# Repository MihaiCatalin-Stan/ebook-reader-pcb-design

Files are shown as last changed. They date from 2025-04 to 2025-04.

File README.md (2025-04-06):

335CA Mihai-Catalin Stan
# OpenBook EBook Reader
This project contains the 2D and 3D Hardware design of an ebook reader, alongside the manufacturing files and some images of the product.
## Block Diagram
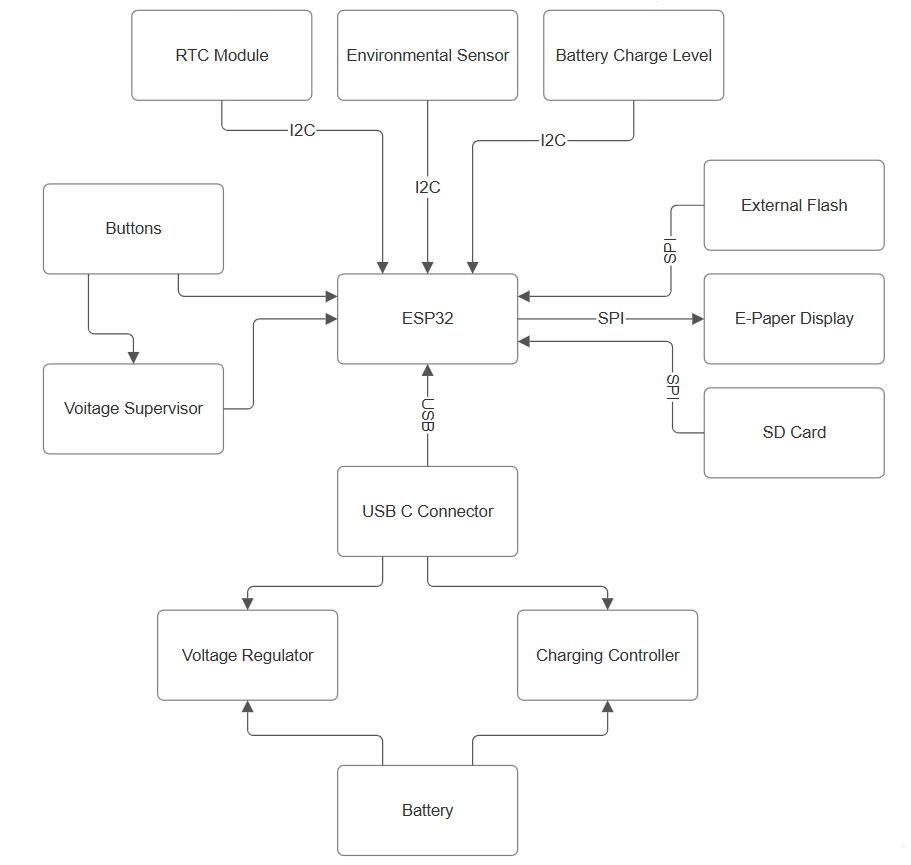
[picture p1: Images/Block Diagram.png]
Block Diagram


## Bill of Materials
|Component|Description|Buy Here|Datasheet|
|---|---|---|---|
|ESP32_WROVER_EAGLE-LTSPICE_RR0402 | Resistor | https://eu.mouser.com/ProductDetail/Vishay-Beyschlag/MCS04020D9101BE000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  | https://www.vishay.com/docs/28700/mcx0x0xpre.pdf
|EAGLE-LTSPICE_CC0402 | Capacitor | https://eu.mouser.com/ProductDetail/KEMET/C0402C475K8PACTU?qs=ulEaXIWI0c9ebKRT3r3htg%3D%3D | https://eu.mouser.com/datasheet/2/447/KEM_C1006_X5R_SMD-3316465.pdf
|ESP32C6_VARISTORCN1812 | Varistor | https://eu.mouser.com/ProductDetail/Schurter/PFMF.050.2?qs=1auRipcfynCums5v1iucSA%3D%3D | https://eu.mouser.com/datasheet/2/358/typ_PFMF-1275918.pdf
|CPH3225A | Capacitor | https://eu.mouser.com/ProductDetail/Seiko-Semiconductors/CPH3225A?qs=3etwrb1wR%252BhUOph6lAO7eg%3D%3D | https://eu.mouser.com/datasheet/2/360/Seiko_Instruments_MicroBattery_E_20230330_2024Jan_-3561061.pdf
|RCL_CPOL-EUCT3528 | Capacitor | https://eu.mouser.com/ProductDetail/Nichicon/LGN2W101MELA25?qs=Fe64Qgzkstf1zMszMsgRoA%3D%3D | https://eu.mouser.com/datasheet/2/293/e_lgn-3082370.pdf
|ADAFRUIT_LEDCHIP-LED0603 | LED | https://eu.mouser.com/ProductDetail/ams-OSRAM/KG-EELP41.22-PHRH-35-A8J8-20-R18?qs=ZcfC38r4Posajg8ZvCDQkg%3D%3D | https://eu.mouser.com/datasheet/2/588/KG_EELP41_22_EN-3572852.pdf
|ESP32_WROVER_SPARKFUN-DISCRETESEMI_MOSFET_PCH-DMG2305UX-7 | Transistor | https://eu.mouser.com/ProductDetail/Diodes-Incorporated/DMG2305UX-7?qs=L1DZKBg7t5F%2FNBHrjfxC%252Bg%3D%3D | https://www.diodes.com/assets/Datasheets/DMG2305UX.pdf
|SI1308EDL-T1-GE3 | Transistor | https://eu.mouser.com/ProductDetail/Vishay-Semiconductors/SI1308EDL-T1-GE3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 | https://www.vishay.com/docs/63399/si1308edl.pdf
| 744043680IND_4828-WE-TPC_WRE | Coil | https://eu.mouser.com/ProductDetail/Wurth-Elektronik/744043680?qs=PGXP4M47uW6VkZq%252BkzjrHA%3D%3D | https://www.we-online.com/components/products/datasheet/744043680.pdf
|112A-TAAR-R03_ATTEND | SD Card Mount | https://store.comet.srl.ro/Catalogue/Product/43497/ | https://store.comet.srl.ro/Catalogue/Product/43497/
|SAMACSYS_PARTS_USB4110-GF-A | USB Connector | https://eu.mouser.com/ProductDetail/GCT/USB4110-GF-A?qs=KUoIvG%2F9IlYiZvIXQjyJeA%3D%3D | https://eu.mouser.com/datasheet/2/837/GCT_USB4110_Product_Drawing___20k_cycles-3455479.pdf
|XC6220A331MR-G | LDO Voltage Regulator | https://eu.mouser.com/ProductDetail/Torex-Semiconductor/XC6220A331MR-G?qs=AsjdqWjXhJ8ZSWznL1J0gg%3D%3D | https://eu.mouser.com/datasheet/2/760/xc6220-3371556.pdf
|W25Q512JVEIQ | Flash Memory | https://eu.mouser.com/ProductDetail/Winbond/W25Q512JVEIQ?qs=l7cgNqFNU1jw6svr3at6tA%3D%3D | https://eu.mouser.com/datasheet/2/949/Winbond_W25Q512JV_Datasheet-3240039.pdf
|USBLC6-2SC6Y | ESD Protection | https://eu.mouser.com/ProductDetail/STMicroelectronics/USBLC6-2SC6Y?qs=gNDSiZmRJS%2FOgDexvXkdow%3D%3D | https://eu.mouser.com/datasheet/2/389/usblc6_2sc6y-1852505.pdf
|MCP73831 | Battery Controller | https://eu.mouser.com/ProductDetail/Microchip-Technology/MCP73831T-2ATI-MC?qs=yUQqVecv4qs9k7ug0bEXiw%3D%3D | https://eu.mouser.com/datasheet/2/268/MCP73831_Family_Data_Sheet_DS20001984H-3441711.pdf
|MAX17048G+T10 | Battery Management | https://eu.mouser.com/ProductDetail/Analog-Devices-Maxim-Integrated/MAX17048G%2bT10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 | https://eu.mouser.com/datasheet/2/609/MAX17048_MAX17049-3469099.pdf
|FH34SRJ | E-Paper Display Header | https://eu.mouser.com/ProductDetail/Hirose-Connector/FH34SRJ-7S-0.5SH50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 | https://eu.mouser.com/datasheet/2/185/FH34SRJ_7S_0_5SH_50__CL0580_1200_0_50_2DDrawing_00-1615127.pdf
|ESP32_WROVER_AVX---SD0805S020S1R0_AVX_SD0805S020S1R0_0_0AVX_SD0805S020S1R0_0_0 | Diode | https://eu.mouser.com/ProductDetail/ROHM-Semiconductor/SCS310AMC7G?qs=iLKYxzqNS75xiccEgNnX2g%3D%3D | https://fscdn.rohm.com/en/products/databook/datasheet/discrete/sic/sbd/scs310am-e.pdf
|ESP32-C6-WROOM-1-N8 | MicroController | https://eu.mouser.com/ProductDetail/Espressif-Systems/ESP32-C6?qs=Imq1NPwxi75noDtUpuVuWw%3D%3D | https://eu.mouser.com/datasheet/2/891/esp32_c6_datasheet_en-3304070.pdf
|DS3231SN# | RTC Module | https://eu.mouser.com/ProductDetail/Analog-Devices-Maxim-Integrated/DS3231SN?qs=1eQvB6Dk1vhUlr8%2FOrV0Fw%3D%3D | https://eu.mouser.com/datasheet/2/609/DS3231-3421123.pdf
|ESP32_WROVER_BME680_BME680 | Integrated Environmental Unit | https://eu.mouser.com/ProductDetail/M5Stack/U001-C?qs=e8oIoAS2J1R2mB7ZY1%252BSZg%3D%3D | https://docs.m5stack.com/en/unit/envIII
| BD5229G-TR | Voltage Detector | https://eu.mouser.com/ProductDetail/ROHM-Semiconductor/BD5229G-TR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 | https://fscdn.rohm.com/en/products/databook/datasheet/ic/power/voltage_detector/bd52xxg-e.pdf

## Hardware Details
* **MicroController - ESP32-C6-WROOM-1-N8:**
    * Pins are being used to communicate as follows:
        | Pin  | Signal       | Connected Component |
        |------|--------------|---------------------|
        | IO00 | INT_RTC      | RTC Module          |
        | IO01 | 32KHZ        | RTC Module          |
        | IO02 | MISO         | Flash, SD Card      |
        | IO03 | EPD_BUSY     | EPD                 |
        | IO04 | SS_SD        | SD Card             |
        | IO05 | EPD_DC       | EPD                 |
        | IO06 | SCK          | Flash, SD Card, BME688 |
        | IO07 | MOSI         | Flash, SD Card, EPD |
        | IO08 | GPIO8 / GND  | -                   |
        | IO09 | -            | -                   |
        | IO10 | EPD_CS       | EPD                 |
        | IO11 | FLASH_CS     | Flash               |
        | IO12 | USB_D-       | USB_C Connector     |
        | IO13 | USB_D+       | USB_C Connector     |
        | IO15 | IO/CHANGE    | Button              |
        | IO16 | TX           | -                   |
        | IO17 | RX           | -                   |
        | IO18 | RTC_RST      | RTC Module          |
        | IO19 | I2C_PW       | BME688              |
        | IO20 | EPD_3V3_C    | EPD                 |
        | IO21 | SDA          | RTC, BME688, Battery Level |
        | IO22 | SCL          | RTC, BME688, Battery Level |
        | IO23 | EPD_RST      | EPD                 |
    * The following Communication Protocols were used:
        | Protocol | Components |
        |----------|------------|
        | I2C      | RTC, BME688, Battery Level |
        | SPI      | Flash, SD Card, EPD |
        | USB      | USB_C Connector (Power) |
* **RTC Module:**
    * Communicates through `I2C` with the uC
        | Pin  | Signal       |
        |------|--------------|
        |Pin1| 32KHZ|
        |Pin3| INT_RTC|
        |Pin4| RTC_RST|
        |Pin14| VRTC|
        |Pin15| SDA|
        |Pin16| SCL|
* **Flash Module:**
    * Communicates through `SPI` with the uC and the other connected components
        | Pin  | Signal       |
        |------|--------------|
        |Pin1| FLASH_CS|
        |Pin2| MISO|
        |Pin5| MOSI|
        |Pin6| SCK|
* **SD Card Module:**
    * Communicates through `SPI` with the uC and the other connected components
        | Pin  | Signal       |
        |------|--------------|
        |P2| SS_SD|
        |P3| MOSI|
        |P5| SCK|
        |P7| MISO|
* **E-Paper Display:**
    * Communicates through `SPI` with the uC and the memory modules
        | Pin  | Signal       |
        |------|--------------|
        |Pin2| GDR|
        |Pin3| RESE|
        |Pin9| EPD_BUSY|
        |Pin10| EPD_RST|
        |Pin11| EPD_DC|
        |Pin12| EPD_CS|
        |Pin13| SCK|
        |Pin14| MOSI|
        |Pin15-16| EPD_3v3|
        |Pin21| PREVGH|
        |Pin23| PREVGL|
* **Battery Sensor:**
    * Checks the battery level and send data to the uC also with `I2C`
        | Pin  | Signal       |
        |------|--------------|
        |Pin2| VBAT|
        |Pin3| VBAT|
        |Pin7| SCL|
        |Pin8| SDA|
* **LDO - Voltage Regulator:**
    * Doesn't communicate with the uC but lowers the 5V to 3.3V for the uC and the attached modules
* **Environmental Sensor:**
    * Communicates through `I2C` with the uC and also with the RTC
        | Pin  | Signal       |
        |------|--------------|
        |Pin2| I2C_PW|
        |Pin3| SDA|
        |Pin4| SCL|
        |Pin6| I2C_PW|
        |Pin8| I2C_PW|
* **USB-C Connector:**
    * Power input for charging the battery
        | Pin  | Signal       |
        |------|--------------|
        |B4| VUSB|
        |B6| DP|
        |B7| DN|
        |B9| VUSB|
        |A4| VUSB|
        |A6| DP|
        |A7| DN|
        |A9| VUSB|
* **Buttons:**
    * Controls reset, boot and io/change signals by sending them to the uC when pressed

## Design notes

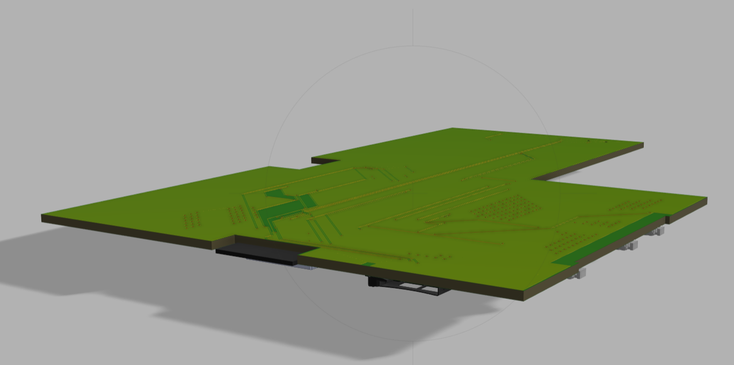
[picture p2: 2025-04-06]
Images/PCB Front View.png

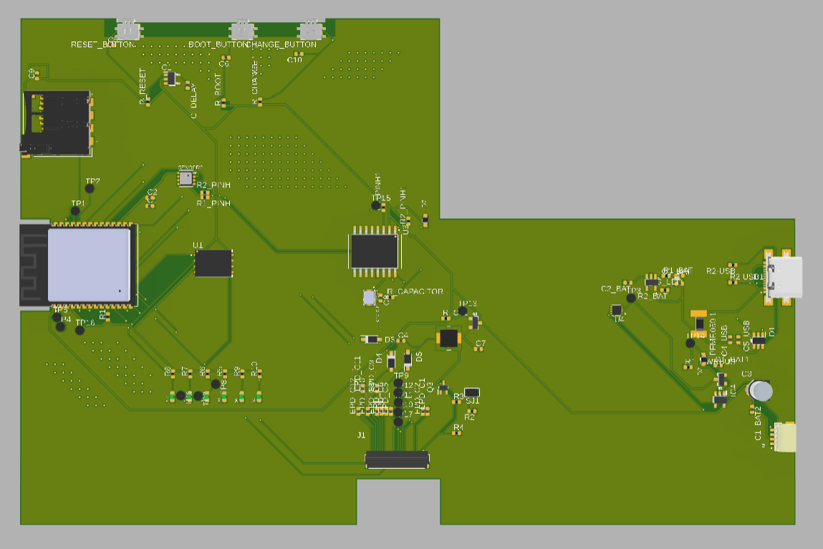
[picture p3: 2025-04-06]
Images/PCB Ortographic Top Layer.png

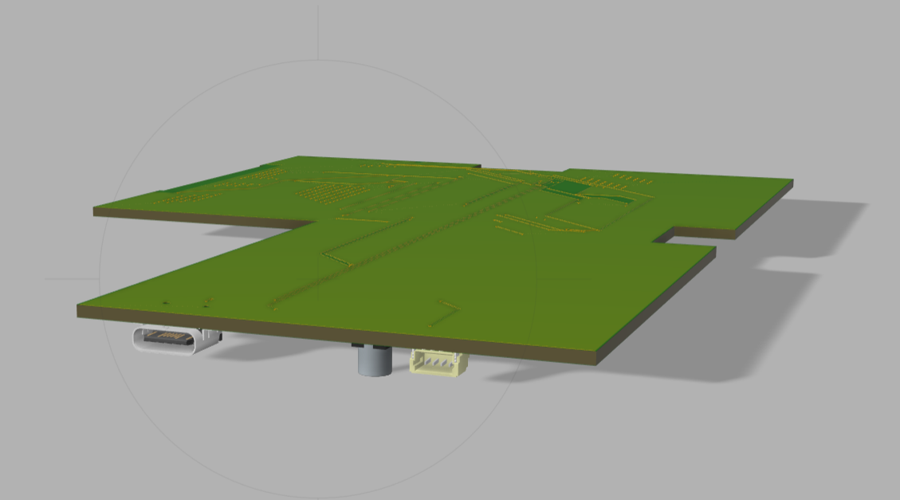
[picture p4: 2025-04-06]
Images/PCB Back View.png

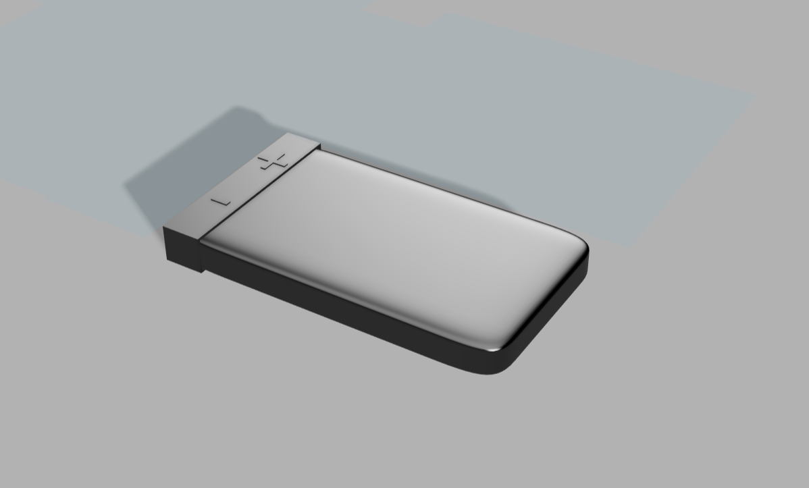
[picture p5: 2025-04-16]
Images/Battery.png

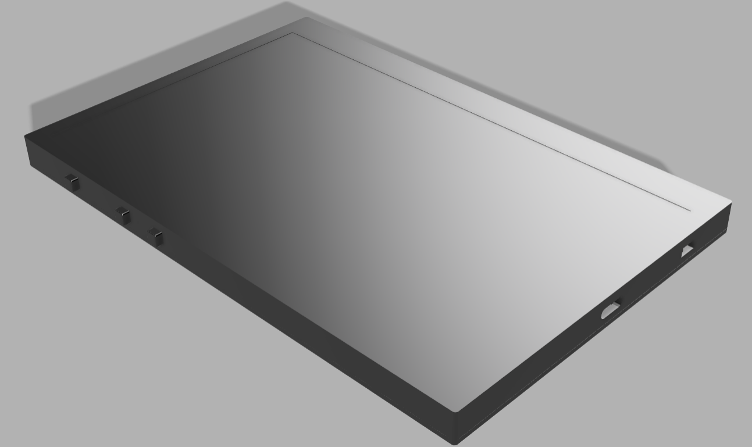
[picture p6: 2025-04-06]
Images/OpenBook.png

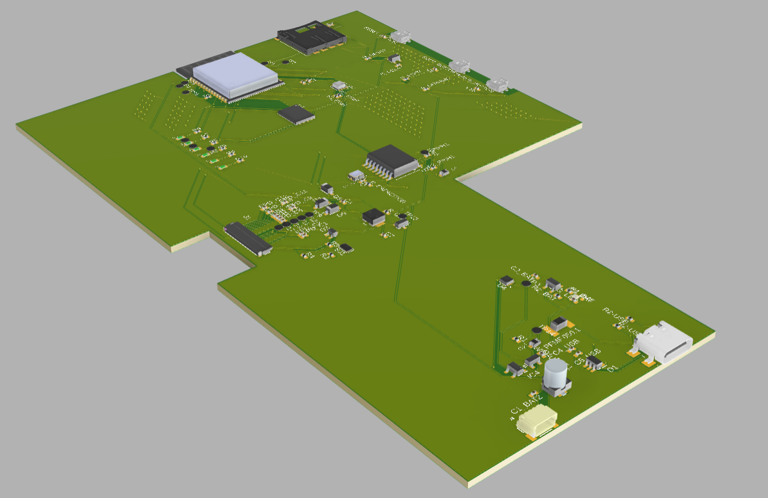
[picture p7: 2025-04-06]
Images/PCB Top Layer.png

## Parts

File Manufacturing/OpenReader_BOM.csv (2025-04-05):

Qty | Value | Device | Package | Parts | Description | ARROW_PART_NUMBER | ARROW_PRICE-STOCK | AVAILABILITY | CHECK_PRICES | COPYRIGHT | DESCRIPTION | HEIGHT | MANUFACTURER_NAME | MANUFACTURER_PART_NUMBER | MF | MFR_NAME | MOUSER_PART_NUMBER | MOUSER_PRICE-STOCK | MOUSER_TESTING_PART_NUMBER | MOUSER_TESTING_PRICE-STOCK | MP | PACKAGE | POPULARITY | PRICE | PROD_ID | PURCHASE-URL | SNAPEDA_LINK | SPICEMODEL | SPICEPREFIX | TP_SIGNAL_NAME | VALUE | LCSC Part Number
1 |  | ADAFRUIT_LEDCHIP-LED0603 | ADAFRUIT_CHIP-LED0603 | CHG_LED | LED
1 |  | SJ | SJ | SJ1 | SMD solder JUMPER |  |  |  |  |  |  |  |  |  |  |  |  |  |  |  |  |  | 3
1 | 0.1uF/50V | EAGLE-LTSPICE_CC0402 | EAGLE-LTSPICE_C0402 | EPD_C5 | CAPACITOR, European symbol |  |  |  |  |  |  |  |  |  |  |  |  |  |  |  |  |  |  |  |  |  |  | NONE | C
1 | 0.47 | ESP32_WROVER_EAGLE-LTSPICE_RR0402 | ESP32_WROVER_EAGLE-LTSPICE_R0402 | R3 | RESISTOR, European symbol
1 | 100K | ESP32_WROVER_EAGLE-LTSPICE_RR0402 | ESP32_WROVER_EAGLE-LTSPICE_R0402 | R1_PWRBUS | RESISTOR, European symbol
8 | 100nF | EAGLE-LTSPICE_CC0402 | EAGLE-LTSPICE_C0402 | C1, C2, C4_USB, C6, C8, C9, C10, C_DELAY | CAPACITOR, European symbol |  |  |  |  |  |  |  |  |  |  |  |  |  |  |  |  |  |  |  |  |  |  | NONE | C
1 | 100uF TANT | RCL_CPOL-EUCT3528 | RCL_CT3528 | C3 | POLARIZED CAPACITOR, European symbol |  |  |  |  |  |  |  |  |  |  |  |  |  |  |  |  |  | 0 |  |  |  |  |  | C
16 | 10K | ESP32_WROVER_EAGLE-LTSPICE_RR0402 | ESP32_WROVER_EAGLE-LTSPICE_R0402 | R1, R1_PINH, R1_PINH1, R2_PINH, R2_PINH1, R4, R5, R6, R7, R8, R9, R10, R_BOOT, R_CHANGE, R_CL1, R_RESET | RESISTOR, European symbol
1 | 10uF | EAGLE-LTSPICE_CC0402 | EAGLE-LTSPICE_C0402 | C7 | CAPACITOR, European symbol |  |  |  |  |  |  |  |  |  |  |  |  |  |  |  |  |  |  |  |  |  |  | NONE | C
1 | 112A-TAAR-R03_ATTEND | 112A-TAAR-R03_ATTEND | 112ATAARR03ATTEND | J4 | Micro SD Card Socket, Push-Push Type, Top Mount, SMT, H=1.83mm, 10u |  |  |  |  |  | Micro SD Card Socket | Push-Push Type | Top Mount | SMT | H=1.83mm | 10u | 1.9mm | ATTEND | 112A-TAAR-R03 ATTEND
1 | 15 | ESP32_WROVER_EAGLE-LTSPICE_RR0402 | ESP32_WROVER_EAGLE-LTSPICE_R0402 | R_CAPACITOR | RESISTOR, European symbol
1 | 1uF | EAGLE-LTSPICE_CC0402 | EAGLE-LTSPICE_C0402 | C5 | CAPACITOR, European symbol |  |  |  |  |  |  |  |  |  |  |  |  |  |  |  |  |  |  |  |  |  |  | NONE | C
9 | 1uF/50V | EAGLE-LTSPICE_CC0402 | EAGLE-LTSPICE_C0402 | EPD_C1, EPD_C2, EPD_C6, EPD_C7, EPD_C8, EPD_C9, EPD_C10, EPD_C11, EPD_C12 | CAPACITOR, European symbol |  |  |  |  |  |  |  |  |  |  |  |  |  |  |  |  |  |  |  |  |  |  | NONE | C
1 | 2.2 | ESP32_WROVER_EAGLE-LTSPICE_RR0402 | ESP32_WROVER_EAGLE-LTSPICE_R0402 | R2 | RESISTOR, European symbol
1 | 200 | ESP32_WROVER_EAGLE-LTSPICE_RR0402 | ESP32_WROVER_EAGLE-LTSPICE_R0402 | R1_BAT | RESISTOR, European symbol
2 | 20V/4.2A/52m?/1.4W | ESP32_WROVER_SPARKFUN-DISCRETESEMI_MOSFET_PCH-DMG2305UX-7 | ESP32_WROVER_SPARKFUN-DISCRETESEMI_SOT23-3 | Q1, Q2 | P-channel MOSFETs
1 | 2K | ESP32_WROVER_EAGLE-LTSPICE_RR0402 | ESP32_WROVER_EAGLE-LTSPICE_R0402 | R2_BAT | RESISTOR, European symbol
5 | 4.7uF | EAGLE-LTSPICE_CC0402 | EAGLE-LTSPICE_C0402 | C1_BAT, C1_BAT1, C1_BAT2, C2_BAT, C5_USB | CAPACITOR, European symbol |  |  |  |  |  |  |  |  |  |  |  |  |  |  |  |  |  |  |  |  |  |  | NONE | C
1 | 4.7uF/25V | EAGLE-LTSPICE_CC0402 | EAGLE-LTSPICE_C0402 | C4 | CAPACITOR, European symbol |  |  |  |  |  |  |  |  |  |  |  |  |  |  |  |  |  |  |  |  |  |  | NONE | C
2 | 5K1 | ESP32_WROVER_EAGLE-LTSPICE_RR0402 | ESP32_WROVER_EAGLE-LTSPICE_R0402 | R2-USB, R2-USB1 | RESISTOR, European symbol
1 | 68uH | 744043680IND_4828-WE-TPC_WRE | IND_4828-WE-TPC_WRE | L1 |  |  |  |  |  | Copyright (C) 2024 Ultra Librarian. All rights reserved. |  |  |  | 744043680 |  | Wurth Electronics
1 | BD5229G-TR | BD5229G-TR | SOT95P280X125-5N | IC1 | Voltage Detector with Adjustable Delay Time: CMOS processes are utilized to develop high precision, low current consumption CMOS reset ICs that allow arbitrary setting of the delay time. The extensive lineup includes both Nch Open Drain and CMOS output types in a wide range of detection voltages (from 2.3V to 6.0V, in 0.1V steps), enabling selection of the ideal solution based on customer requirements. In addition, the entire series is of course both lead-free and RoHS-compliant. |  |  |  |  |  | Voltage Detector with Adjustable Delay Time: CMOS processes are utilized to develop high precision | low current consumption CMOS reset ICs that allow arbitrary setting of the delay time. The extensive lineup includes both Nch Open Drain and CMOS output types in a wide range of detection voltages (from 2.3V to 6.0V | in 0.1V steps) | enabling selection of the ideal solution based on customer requirements. In addition | the entire series is of course both lead-free and RoHS-compliant. | 1.25mm | ROHM Semiconductor | BD5229G-TR |  |  | 755-BD5229G-TR | https://www.mouser.co.uk/ProductDetail/ROHM-Semiconductor/BD5229G-TR?qs=4kLU8WoGk0vvnhrrYwdszw%3D%3D
1 | BME688 | ESP32_WROVER_BME680_BME680 | ESP32_WROVER_BME680_PSON80P300X300X100-8N | SENSOR2 | Integrated Environmental Unit |  |  | Unavailable |  |  | Integrated Environmental Unit |  |  |  | Bosch Sensortec |  |  |  |  |  | BME680 | LGA-8 Bosch Tools |  | None
3 |  |  | MYBUTTON | BOOT_BUTTON, CHANGE_BUTTON, RESET_BUTTON
1 | CPH3225A | CPH3225A | CAPCP3225X100N | C10_SUPERCAP | Cap 0.011F 3.3V 1210 Flat Check availability |  |  | Not in stock | https://www.snapeda.com/parts/CPH3225A/Seiko+Instruments/view-part/?ref=eda |  | 11 mF (EDLC) Supercapacitor 3.3 V 1210 (3225 Metric) - - |  |  |  | Seiko Instruments |  |  |  |  |  | CPH3225A | 1210 Seiko |  | None |  | https://www.snapeda.com/api/url_track_click_mouser/?unipart_id=562593&manufacturer=Seiko Instruments&part_name=CPH3225A&search_term=None | https://www.snapeda.com/parts/CPH3225A/Seiko+Instruments/view-part/?ref=snap
1 | DS3231SN# | DS3231SN# | SOIC127P1032X265-16N | U3 | Real Time Clock Serial 16-Pin SOIC W T/R Check availability |  |  | In Stock | https://www.snapeda.com/parts/DS3231SN%23/Analog+Devices/view-part/?ref=eda |  | Extremely Accurate I2C-Integrated RTC/TCXO/Crystal |  |  |  | Analog Devices |  |  |  |  |  | DS3231SN# | SOIC-16 Maxim |  | None |  | https://www.snapeda.com/api/url_track_click_mouser/?unipart_id=99048&manufacturer=Analog Devices&part_name=DS3231SN#&search_term=None | https://www.snapeda.com/parts/DS3231SN%23/Analog+Devices/view-part/?ref=snap
1 | ESP32-C6-WROOM-1-N8 | ESP32-C6-WROOM-1-N8 | XCVR_ESP32-C6-WROOM-1-N8 | U2 | Check availability |  |  | In Stock | https://www.snapeda.com/parts/ESP32-C6-WROOM-1-N8/Espressif+Systems/view-part/?ref=eda |  | Multiprotocol Modules ESP32-C6 module | Wi-Fi 6 in 2.4 GHz band | Bluetooth 5 | Zigbee 3.0 and Thread. ESP34-WROOM Compatible - ENGINEERING SAMPLE |  |  |  | Espressif Systems |  |  |  |  |  | ESP32-C6-WROOM-1-N8 | None |  | None |  |  | https://www.snapeda.com/parts/ESP32-C6-WROOM-1-N8/Espressif+Systems/view-part/?ref=snap
1 | ESP32C6_VARISTORCN1812 | ESP32C6_VARISTORCN1812 | ESP32C6_VARISTOR_CT/CN1812 | PFMF.050.1 | VARISTOR |  |  |  |  |  |  |  |  |  |  |  |  |  |  |  |  |  | 0
2 | ESP32_WROVER_AVX---SD0805S020S1R0_AVX_SD0805S020S1R0_0_0AVX_SD0805S020S1R0_0_0 | ESP32_WROVER_AVX---SD0805S020S1R0_AVX_SD0805S020S1R0_0_0AVX_SD0805S020S1R0_0_0 | ESP32_WROVER_AVX---SD0805S020S1R0_AVX_SD0805S020S1R0_0 | D2, D7 | Schottky Barrier Rectifier Diode
1 | FH34SRJ-24S-0.5SH_99_ | FH34SRJ-24S-0.5SH_99_ | FH34SRJ24S05SH99 | J1 | (0.50mm) Surface Mount, Right Angle |  |  |  |  |  | 24 Position FFC | FPC Connector Contacts | (0.50mm) Surface Mount | Right Angle | 1.1mm | Hirose | FH34SRJ-24S-0.5SH(99) |  |  | 798-FH34SRJ24S05SH99 | https://www.mouser.co.uk/ProductDetail/Hirose-Connector/FH34SRJ-24S-0.5SH99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
1 | MAX17048G+T10 | MAX17048G+T10 | SON50P200X200X80-9N | U4 | Check availability |  |  | In Stock | https://www.snapeda.com/parts/MAX17048G+T10/Analog+Devices/view-part/?ref=eda |  | 3µA 1-Cell/2-Cell Fuel Gauge with ModelGauge |  |  |  | Analog Devices |  |  |  |  |  | MAX17048G+T10 | TDFN-8 Maxim |  | None |  | https://www.snapeda.com/api/url_track_click_mouser/?unipart_id=329239&manufacturer=Analog Devices&part_name=MAX17048G+T10&search_term=None | https://www.snapeda.com/parts/MAX17048G+T10/Analog+Devices/view-part/?ref=snap
3 |  |  | SOD3716X135N | D3, D4, D5 | ON SEMICONDUCTOR - MBR0530 - DIODE, SCHOTTKY, 0.5A, 30V, SOD-123
1 | MCP73831 | MCP73831 | SOT23-5 | U5 | MCP73831T Li-Ion, Li-Pol Controller |  |  |  |  |  |  |  |  |  |  |  |  |  |  |  |  |  |  |  | IC-09995
6 |  |  | DIOC1608X36N | D6, D8, D9, D10, D11, D12 | Check availability
1 | QWIIC_RIGHT_ANGLE | QWIIC_CONNECTORJS-1MM | JST04_1MM_RA | J3 | SparkFun I2C Standard Qwiic Connector |  |  |  |  |  |  |  |  |  |  |  |  |  |  |  |  |  |  |  | CONN-13694 |  |  |  |  |  | QWIIC_RIGHT_ANGLE
1 | SAMACSYS_PARTS_USB4110-GF-A | SAMACSYS_PARTS_USB4110-GF-A | SAMACSYS_PARTS_USB4110GFA | J2 | CONN USB 2.0 TYPE-C R/A SMT |  |  |  |  |  | CONN USB 2.0 TYPE-C R/A SMT | 3.26mm | GCT (GLOBAL CONNECTOR TECHNOLOGY) | USB4110-GF-A |  |  | 640-USB4110-GF-A | https://www.mouser.co.uk/ProductDetail/GCT/USB4110-GF-A?qs=KUoIvG%2F9IlYiZvIXQjyJeA%3D%3D
1 | SI1308EDL-T1-GE3 | SI1308EDL-T1-GE3 | SOT65P210X110-3N | Q3 | MOSFET N-Ch 30V 1.5A TrenchFET SC70 Vishay Si1308EDL-T1-GE3 N-channel MOSFET Transistor, 1.5 A, 30 V, 3-Pin SC-70 |  |  | In Stock | https://www.snapeda.com/parts/SI1308EDL-T1-GE3/Vishay+Siliconix/view-part/?ref=eda |  | Si1308EDL-T1-GE3 N-channel MOSFET Transistor | 1.5 A | 30 V | 3-Pin SC-70 | Siliconix / Vishay SI1308EDL-T1-GE3 |  |  |  | Vishay Siliconix |  |  |  |  |  | SI1308EDL-T1-GE3 | SOT-323 Vishay Semiconductor |  | None |  | https://www.snapeda.com/api/url_track_click_mouser/?unipart_id=274603&manufacturer=Vishay Siliconix&part_name=SI1308EDL-T1-GE3&search_term=None | https://www.snapeda.com/parts/SI1308EDL-T1-GE3/Vishay+Siliconix/view-part/?ref=snap
17 | TPTP20R | TPTP20R | TP20R | TP1, TP2, TP3, TP4, TP5, TP6, TP7, TP8, TP9, TP10, TP11, TP12, TP13, TP14, TP15, TP16, TP17 | Test pad |  |  |  |  |  |  |  |  |  |  |  |  |  |  |  |  |  | 2
1 | USBLC6-2SC6Y | USBLC6-2SC6Y | SOT95P280X145-6N | D1 | Low Cap. ESD Protection Auto SOT-23-6 STMicroelectronics USBLC6-2SC6Y, Dual Uni-Directional TVS Diode Array, 6-Pin SOT-23 |  |  | In Stock | https://www.snapeda.com/parts/USBLC6-2SC6Y/STMicroelectronics/view-part/?ref=eda |  | 17V Clamp 5A (8/20µs) Ipp Tvs Diode Surface Mount SOT-23-6 |  |  |  | STMicroelectronics |  |  |  |  |  | USBLC6-2SC6Y | SOT-23-6 STMicroelectronics |  | None |  |  | https://www.snapeda.com/parts/USBLC6-2SC6Y/STMicroelectronics/view-part/?ref=snap
1 | W25Q512JVEIQ | W25Q512JVEIQ | SON127P600X800X80-9N | U1 | Check availability |  |  | In Stock | https://www.snapeda.com/parts/W25Q512JVEIQ/Winbond+Electronics/view-part/?ref=eda |  | FLASH - NOR Memory IC 512Mb (64M x 8) SPI - Quad I/O 133 MHz 8-WSON (8x6) |  |  |  | Winbond Electronics |  |  |  |  |  | W25Q512JVEIQ | Package |  | None |  |  | https://www.snapeda.com/parts/W25Q512JVEIQ/Winbond+Electronics/view-part/?ref=snap
1 | XC6220A331MR-G | XC6220A331MR-G | SOT95P280X120-5N | IC4 | LDO Voltage Regulators |  |  |  |  |  | LDO Voltage Regulators | 1.2mm | Torex | XC6220A331MR-G |  |  | 865-XC6220A331MR-G | https://www.mouser.co.uk/ProductDetail/Torex-Semiconductor/XC6220A331MR-G?qs=AsjdqWjXhJ8ZSWznL1J0gg%3D%3D

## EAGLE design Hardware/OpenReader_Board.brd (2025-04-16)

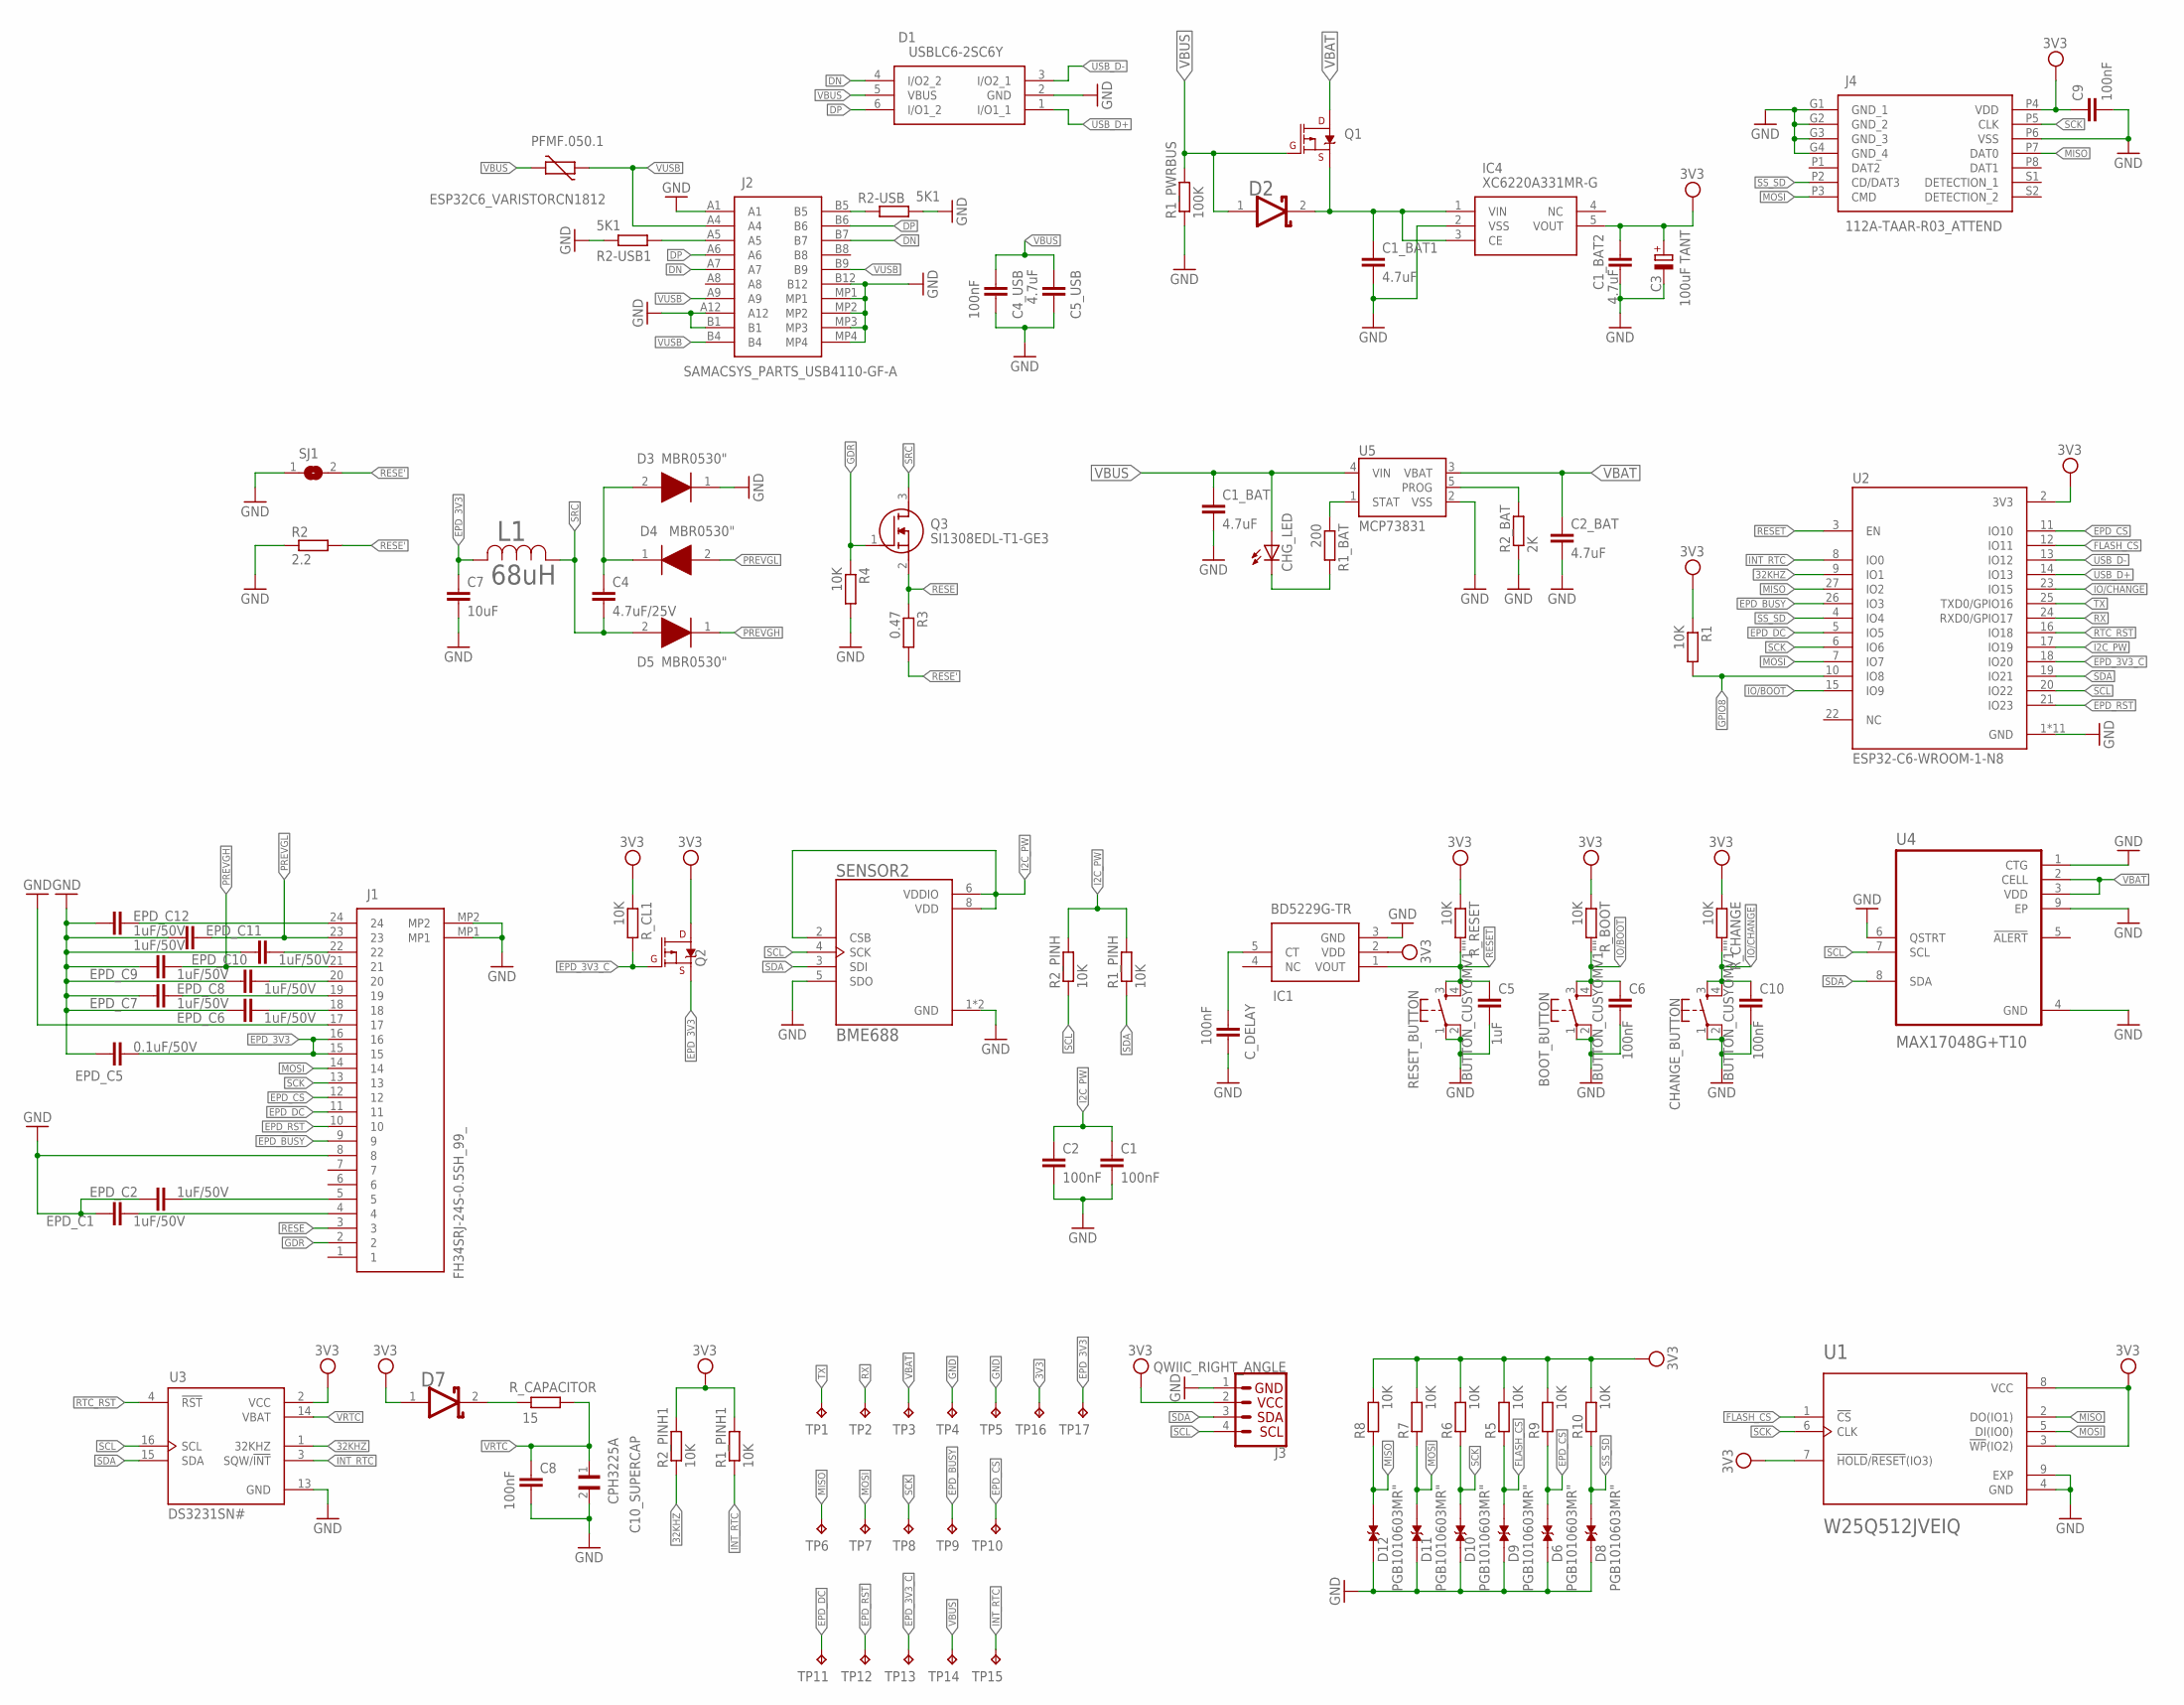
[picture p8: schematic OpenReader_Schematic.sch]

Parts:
BOOT_BUTTON: BUTTON_CUSYOMV1""; MYBUTTON
C1, C2, C4_USB, C6, C8, C9, C10: 100nF; EAGLE-LTSPICE_C0402
C1_BAT, C1_BAT1, C1_BAT2, C2_BAT, C5_USB: 4.7uF; EAGLE-LTSPICE_C0402
C3: 100uF TANT; RCL_CT3528
C4: 4.7uF/25V; EAGLE-LTSPICE_C0402
C5: 1uF; EAGLE-LTSPICE_C0402
C7: 10uF; EAGLE-LTSPICE_C0402
C10_SUPERCAP: CPH3225A; CAPCP3225X100N
CHANGE_BUTTON: BUTTON_CUSYOMV1""; MYBUTTON
CHG_LED: ADAFRUIT_LEDCHIP-LED0603; ADAFRUIT_CHIP-LED0603
C_DELAY: 100nF; EAGLE-LTSPICE_C0402
D1: USBLC6-2SC6Y; SOT95P280X145-6N
D2, D7: ESP32_WROVER_AVX---SD0805S020S1R0_AVX_SD0805S020S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; ESP32_WROVER_AVX---SD0805S020S1R0_AVX_SD0805S020S1R0_0
D3, D4, D5: MBR0530"; SOD3716X135N
D6, D8, D9, D10, D11, D12: PGB1010603MR"; DIOC1608X36N
EPD_C1, EPD_C2, EPD_C6, EPD_C7, EPD_C8, EPD_C9, EPD_C10, EPD_C11, EPD_C12: 1uF/50V; EAGLE-LTSPICE_C0402
EPD_C5: 0.1uF/50V; EAGLE-LTSPICE_C0402
IC1: BD5229G-TR; SOT95P280X125-5N
IC4: XC6220A331MR-G; SOT95P280X120-5N
J1: FH34SRJ-24S-0.5SH_99_; FH34SRJ24S05SH99
J2: SAMACSYS_PARTS_USB4110-GF-A; SAMACSYS_PARTS_USB4110GFA
J3: QWIIC_RIGHT_ANGLE; JST04_1MM_RA
J4: 112A-TAAR-R03_ATTEND; 112ATAARR03ATTEND
L1: 68uH; IND_4828-WE-TPC_WRE
PFMF.050.1: ESP32C6_VARISTORCN1812; ESP32C6_VARISTOR_CT/CN1812
Q1, Q2: 20V/4.2A/52mΩ/1.4W; ESP32_WROVER_SPARKFUN-DISCRETESEMI_SOT23-3
Q3: SI1308EDL-T1-GE3; SOT65P210X110-3N
R1, R1_PINH, R1_PINH1, R2_PINH, R2_PINH1, R4, R5, R6, R7, R8, R9, R10: 10K; ESP32_WROVER_EAGLE-LTSPICE_R0402
R1_BAT: 200; ESP32_WROVER_EAGLE-LTSPICE_R0402
R1_PWRBUS: 100K; ESP32_WROVER_EAGLE-LTSPICE_R0402
R2: 2.2; ESP32_WROVER_EAGLE-LTSPICE_R0402
R2-USB, R2-USB1: 5K1; ESP32_WROVER_EAGLE-LTSPICE_R0402
R2_BAT: 2K; ESP32_WROVER_EAGLE-LTSPICE_R0402
R3: 0.47; ESP32_WROVER_EAGLE-LTSPICE_R0402
RESET_BUTTON: BUTTON_CUSYOMV1""; MYBUTTON
R_BOOT: 10K; ESP32_WROVER_EAGLE-LTSPICE_R0402
R_CAPACITOR: 15; ESP32_WROVER_EAGLE-LTSPICE_R0402
R_CHANGE: 10K; ESP32_WROVER_EAGLE-LTSPICE_R0402
R_CL1: 10K; ESP32_WROVER_EAGLE-LTSPICE_R0402
R_RESET: 10K; ESP32_WROVER_EAGLE-LTSPICE_R0402
SENSOR2: BME688; ESP32_WROVER_BME680_PSON80P300X300X100-8N
SJ1: SJ
TP1, TP2, TP3, TP4, TP5, TP6, TP7, TP8, TP9, TP10, TP11, TP12, TP13, TP14, TP15, TP16, TP17: TPTP20R; TP20R
U1: W25Q512JVEIQ; SON127P600X800X80-9N
U2: ESP32-C6-WROOM-1-N8; XCVR_ESP32-C6-WROOM-1-N8
U3: DS3231SN#; SOIC127P1032X265-16N
U4: MAX17048G+T10; SON50P200X200X80-9N
U5: MCP73831; SOT23-5

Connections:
3V3: C1_BAT2.1, C3.+, C9.1, D7.1 (ANODE), IC1.2 (VDD), IC4.5 (VOUT), J3.2, J4.P4 (VDD), Q2.3 (D), R1.1, R1_PINH1.2, R2_PINH1.2, R5.2, R6.2, R7.2, R8.2, R9.2, R10.2, R_BOOT.1, R_CHANGE.1, R_CL1.1, R_RESET.1, TP16.TP, U1.3 (!WP!(IO2)), U1.7 (!HOLD!/!RESET!(IO3)), U1.8 (VCC), U2.2 (3V3), U3.2 (VCC)
32KHZ: R2_PINH1.1, U2.9 (IO1), U3.1 (32KHZ)
DN: D1.4 (I/O2_2), J2.A7, J2.B7
DP: D1.6 (I/O1_2), J2.A6, J2.B6
EPD_3V3: C7.1, EPD_C5.1, J1.15, J1.16, L1.2, Q2.2 (S), TP17.TP
EPD_3V3_C: Q2.1 (G), R_CL1.2, TP13.TP, U2.18 (IO20)
EPD_BUSY: J1.9, TP9.TP, U2.26 (IO3)
EPD_CS: D6.2, J1.12, R9.1, TP10.TP, U2.11 (IO10)
EPD_DC: J1.11, TP11.TP, U2.5 (IO5)
EPD_RST: J1.10, TP12.TP, U2.21 (IO23)
FLASH_CS: D9.2, R5.1, U1.1 (!CS), U2.12 (IO11)
GDR: J1.2, Q3.1 (G), R4.1
GND: BOOT_BUTTON.1, BOOT_BUTTON.2, C1.2, C1_BAT.2, C1_BAT1.2, C1_BAT2.2, C2.2, C2_BAT.2, C3.-, C4_USB.2, C5.2, C5_USB.2, C6.2, C7.2, C8.2, C9.2, C10.2, C10_SUPERCAP.2, CHANGE_BUTTON.1, CHANGE_BUTTON.2, C_DELAY.2, D1.2 (GND), D3.1 (K), D6.1, D8.1, D9.1, D10.1, D11.1, D12.1, EPD_C1.2, EPD_C2.2, EPD_C5.2, EPD_C6.2, EPD_C7.2, EPD_C8.2, EPD_C9.2, EPD_C10.2, EPD_C11.2, EPD_C12.2, IC1.3 (GND), IC4.2 (VSS), J1.8, J1.17, J1.MP1, J1.MP2, J2.A1, J2.A12, J2.B1, J2.B12, J2.MP1, J2.MP2, J2.MP3, J2.MP4, J3.1, J4.G1 (GND_1), J4.G2 (GND_2), J4.G3 (GND_3), J4.G4 (GND_4), J4.P6 (VSS), R1_PWRBUS.1, R2.1, R2-USB.2, R2-USB1.1, R2_BAT.1, R4.2, RESET_BUTTON.1, RESET_BUTTON.2, SENSOR2.1 (GND), SENSOR2.5 (SDO), SENSOR2.7 (GND), SJ1.1, TP4.TP, TP5.TP, U1.4 (GND), U1.9 (EXP), U2.1 (GND), U2.28 (GND), U2.29_1 (GND), U2.29_2 (GND), U2.29_3 (GND), U2.29_4 (GND), U2.29_5 (GND), U2.29_6 (GND), U2.29_7 (GND), U2.29_8 (GND), U2.29_9 (GND), U3.13 (GND), U4.1 (CTG), U4.4 (GND), U4.6 (QSTRT), U4.9 (EP), U5.2 (VSS)
GPIO8: R1.2, U2.10 (IO8)
I2C_PW: C1.1, C2.1, R1_PINH.2, R2_PINH.2, SENSOR2.2 (CSB), SENSOR2.6 (VDDIO), SENSOR2.8 (VDD), U2.17 (IO19)
INT_RTC: R1_PINH1.1, TP15.TP, U2.8 (IO0), U3.3 (SQW/!INT)
IO/BOOT: BOOT_BUTTON.3, BOOT_BUTTON.4, C6.1, R_BOOT.2, U2.15 (IO9)
IO/CHANGE: C10.1, CHANGE_BUTTON.3, CHANGE_BUTTON.4, R_CHANGE.2, U2.23 (IO15)
MISO: D12.2, J4.P7 (DAT0), R8.1, TP6.TP, U1.2 (DO(IO1)), U2.27 (IO2)
MOSI: D11.2, J1.14, J4.P3 (CMD), R7.1, TP7.TP, U1.5 (DI(IO0)), U2.7 (IO7)
unnamed: R1_BAT.1, U5.1 (STAT)
unnamed: CHG_LED.C, R1_BAT.2
unnamed: C1_BAT1.1, D2.2 (CATHODE), IC4.1 (VIN), IC4.3 (CE), Q1.2 (S)
unnamed: R2_BAT.2, U5.5 (PROG)
unnamed: J2.A5, R2-USB1.2
unnamed: C_DELAY.1, IC1.5 (CT)
unnamed: C4.1, D3.2 (A), D4.1 (K)
unnamed: EPD_C12.1, J1.24
unnamed: EPD_C10.1, J1.22
unnamed: EPD_C8.1, J1.20
unnamed: J2.B5, R2-USB.1
unnamed: EPD_C7.1, J1.19
unnamed: EPD_C6.1, J1.18
unnamed: EPD_C2.1, J1.5
unnamed: EPD_C1.1, J1.4
unnamed: D7.2 (CATHODE), R_CAPACITOR.2
PREVGH: D5.1 (K), EPD_C9.1, J1.21
PREVGL: D4.2 (A), EPD_C11.1, J1.23
RESE: J1.3, Q3.2 (S), R3.1
RESE': R2.2, R3.2, SJ1.2
RESET: C5.1, IC1.1 (VOUT), RESET_BUTTON.3, RESET_BUTTON.4, R_RESET.2, U2.3 (EN)
RTC_RST: U2.16 (IO18), U3.4 (!RST)
RX: TP2.TP, U2.24 (RXD0/GPIO17)
SCK: D10.2, J1.13, J4.P5 (CLK), R6.1, TP8.TP, U1.6 (CLK), U2.6 (IO6)
SCL: J3.4, R2_PINH.1, SENSOR2.4 (SCK), U2.20 (IO22), U3.16 (SCL), U4.7 (SCL)
SDA: J3.3, R1_PINH.1, SENSOR2.3 (SDI), U2.19 (IO21), U3.15 (SDA), U4.8 (SDA)
SRC: C4.2, D5.2 (A), L1.1, Q3.3 (D)
SS_SD: D8.2, J4.P2 (CD/DAT3), R10.1, U2.4 (IO4)
TX: TP1.TP, U2.25 (TXD0/GPIO16)
USB_D+: D1.1 (I/O1_1), U2.14 (IO13)
USB_D-: D1.3 (I/O2_1), U2.13 (IO12)
VBAT: C2_BAT.1, Q1.3 (D), TP3.TP, U4.2 (CELL), U4.3 (VDD), U5.3 (VBAT)
VBUS: C1_BAT.1, C4_USB.1, C5_USB.1, CHG_LED.A, D1.5 (VBUS), D2.1 (ANODE), PFMF.050.1.2, Q1.1 (G), R1_PWRBUS.2, TP14.TP, U5.4 (VIN)
VRTC: C8.1, C10_SUPERCAP.1, R_CAPACITOR.1, U3.14 (VBAT)
VUSB: J2.A4, J2.A9, J2.B4, J2.B9, PFMF.050.1.1

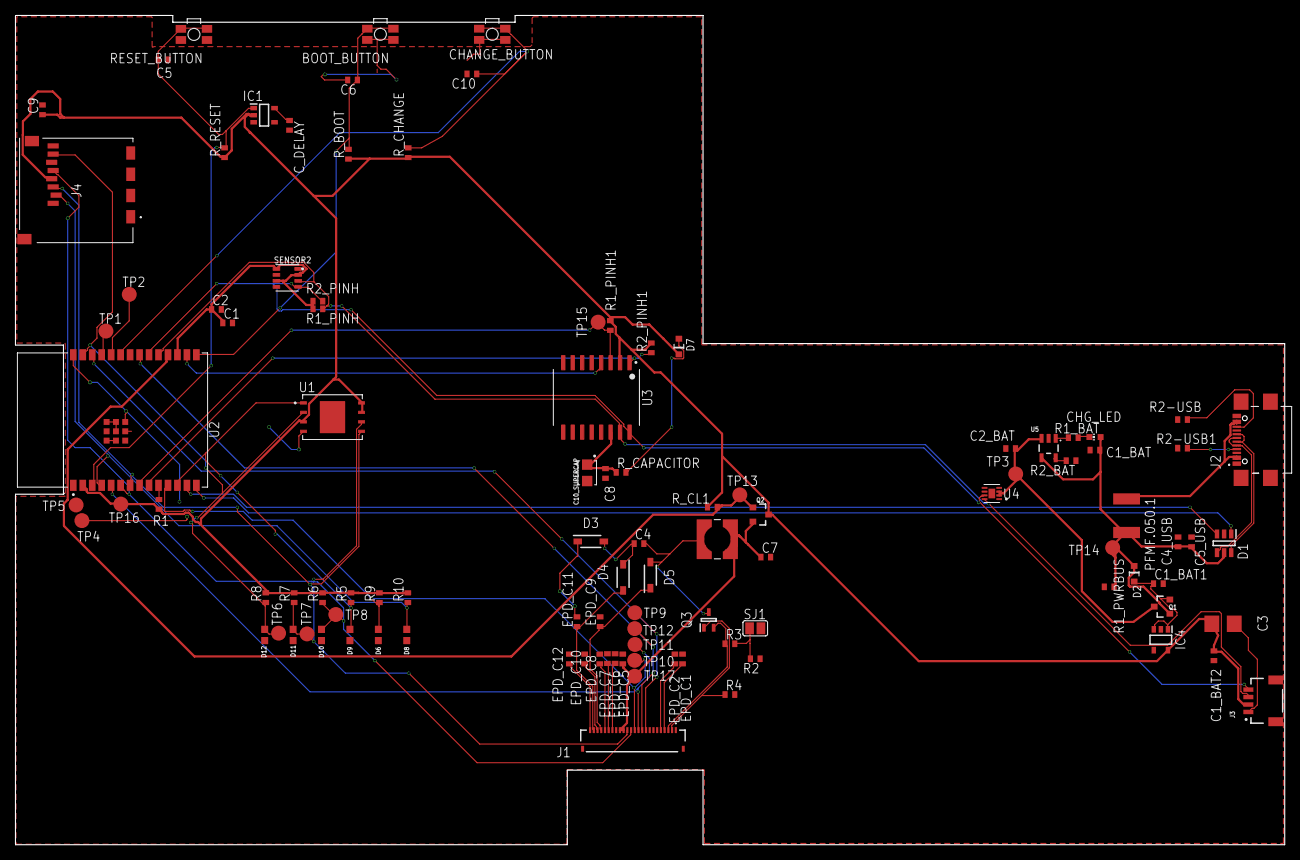
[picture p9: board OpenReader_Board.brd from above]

Board: 2 copper layers, 170.2 x 111.2 mm, 103 parts (0 on the bottom side), 55 nets.

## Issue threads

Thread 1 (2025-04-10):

Model 3D

RobertP1021, 2025-04-10:
Display-ul 3D ar trebui modificat conform dimensiunilor precizate in cerinta. (170.2 (H)×111.2(V) ×1.18(D) mm)

MihaiCatalin-Stan, 2025-04-16:
Modified 3D display according to the datasheet and the constraints of the casing. Now the display is made out of 4 elements and their thickness sums up to a total of 1.175mm

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

Aditionally added battery casing and +/- symbols according to the requirements of the project and the datasheet.

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

Closed 2025-04-16.

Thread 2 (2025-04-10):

PCB - Plan de masa

RobertP1021, 2025-04-10:
Completarea planurilor de masa cu via-uri de GND pentru a completa gaurile existente.

MihaiCatalin-Stan, 2025-04-15:
Fixed empty patches in ground plane, both on top layer and bottom layer. Attaching screenshots for reference

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

Closed 2025-04-15.

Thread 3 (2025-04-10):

PCB - Rutare

RobertP1021, 2025-04-10:
Modificarea aparitiei unghiurilor drepte in rutare. (3v3, miso langa esp)

MihaiCatalin-Stan, 2025-04-15:
Modified 3V3, MISO and a few other wires on both top and bottom that had right (90 degrees) angles. Attaching one example of fixed wires.

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

Closed 2025-04-15.

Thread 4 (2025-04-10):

PCB - Dimensiuni

RobertP1021, 2025-04-10:
Ajustarea dimensiunilor placutei la dimensiunile specificate, pentru compatibilitatea cu carcasa.

MihaiCatalin-Stan, 2025-04-15:
***Issue Solved!***

Modified the dielectric thickness to only 1mm from 1.6mm to fit the total board thickness in the given parameters!

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

Closed 2025-04-15.

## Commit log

2025-04-05 Added Manufacturing, Mechanical and Hardware data for the project
    Added the schematic and pcb design for the project in the Hardware section.
    Added the manufacturing files such as gerbers, pick n place and bill of materials in the Manufacturing section.
    Added the 3D model of the whole product and the exploded view of it in the Mechanical section.
    [OpenReader_BOM.csv, OpenReader_Board.brd, OpenReader_Schematic.sch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]
2025-04-06 Added readme
    Added a readme containing data about the project, a block diagram, the BOM with all the required links and some general info about the hardware
2025-04-16 Fixed reported issues and aditionally modified battery design and gerbers archive
    - Fixed right angles
    - Filled GND plane empty patches
    - Created new and improved Display 3D design and battery 3D design
    - Modified the board's dimensions
    - Modified silkscreen to be more visible/readable
    [OpenReader_Board.brd]

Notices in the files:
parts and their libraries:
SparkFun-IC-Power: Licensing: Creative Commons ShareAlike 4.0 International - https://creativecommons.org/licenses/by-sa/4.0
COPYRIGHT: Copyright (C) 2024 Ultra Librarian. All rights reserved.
